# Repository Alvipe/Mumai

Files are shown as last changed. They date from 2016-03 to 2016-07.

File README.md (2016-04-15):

# Mumai
Mumai is a muscle-machine interface which uses EMG signals to control electronic or mechatronic devices.

<p align="center">
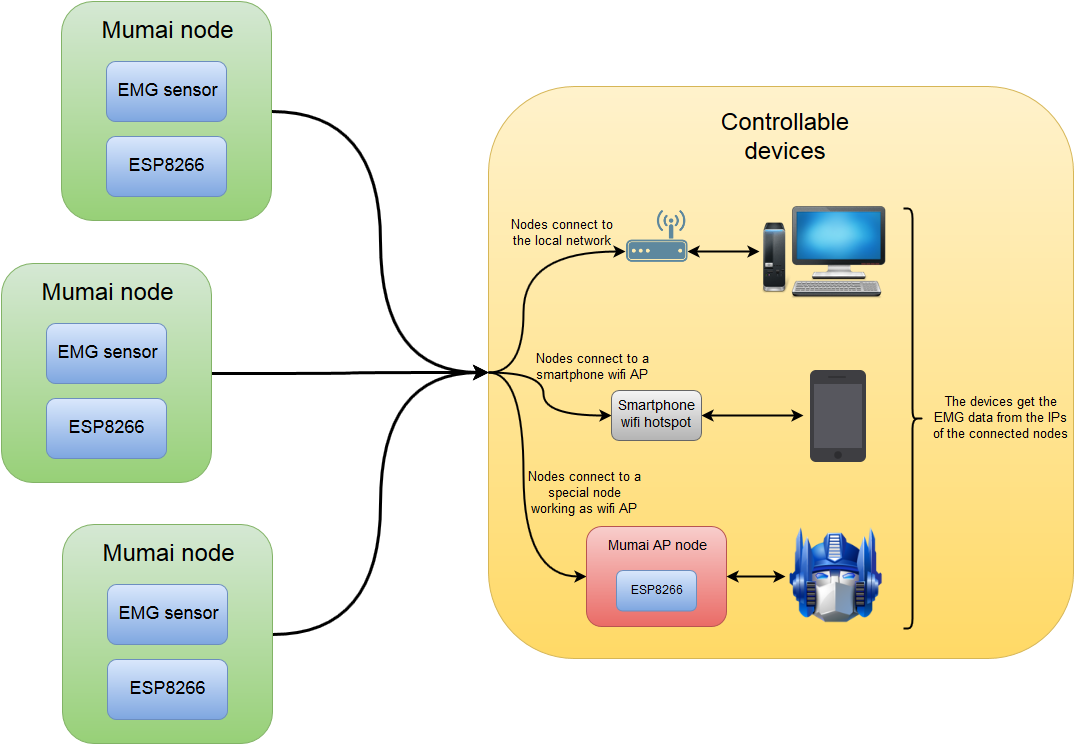
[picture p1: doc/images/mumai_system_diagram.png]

</p>

# License
<br />This work is licensed under a <a rel="license" href="http://creativecommons.org/licenses/by-sa/4.0/">Creative Commons Attribution-ShareAlike 4.0 International License</a>.

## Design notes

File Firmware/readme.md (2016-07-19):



To upload the firmware, use [PlatformIO](http://platformio.org/).

```bash
~/Mumai$ cd Firmware/NodeMCU
~/Mumai/Firmware/NodeMCU$ platformio run --target upload
```

The *mumai_testing.ino* file inside the *src* directory can also be uploaded with the Arduino IDE.

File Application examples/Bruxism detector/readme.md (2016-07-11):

To upload the firmware, use [PlatformIO](http://platformio.org/).

```bash
~/Mumai$ cd "Application examples"/"Bruxism detector"
~/Mumai/Application examples/Bruxism detector$ platformio run --target upload
```

The *bruxism_detector.ino* file inside the *src* directory can also be uploaded with the Arduino IDE.

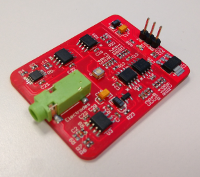
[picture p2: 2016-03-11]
doc/images/mumai.png

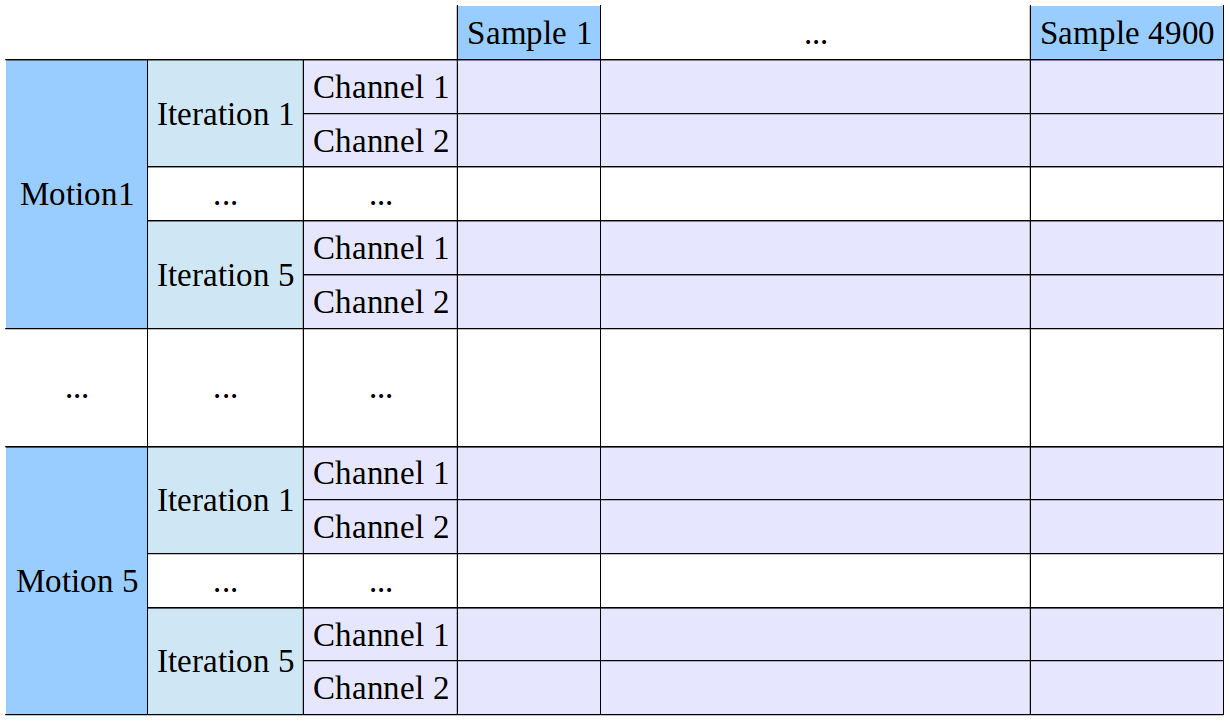
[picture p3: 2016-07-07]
doc/images/emg_data_matrix.png

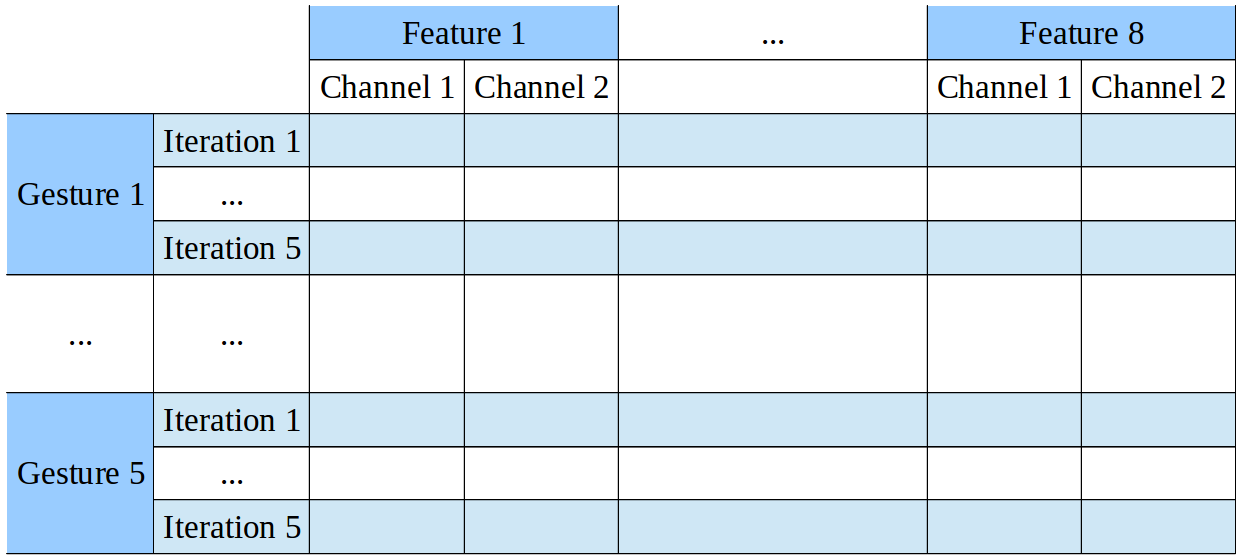
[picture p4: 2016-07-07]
doc/images/feature_matrix.png

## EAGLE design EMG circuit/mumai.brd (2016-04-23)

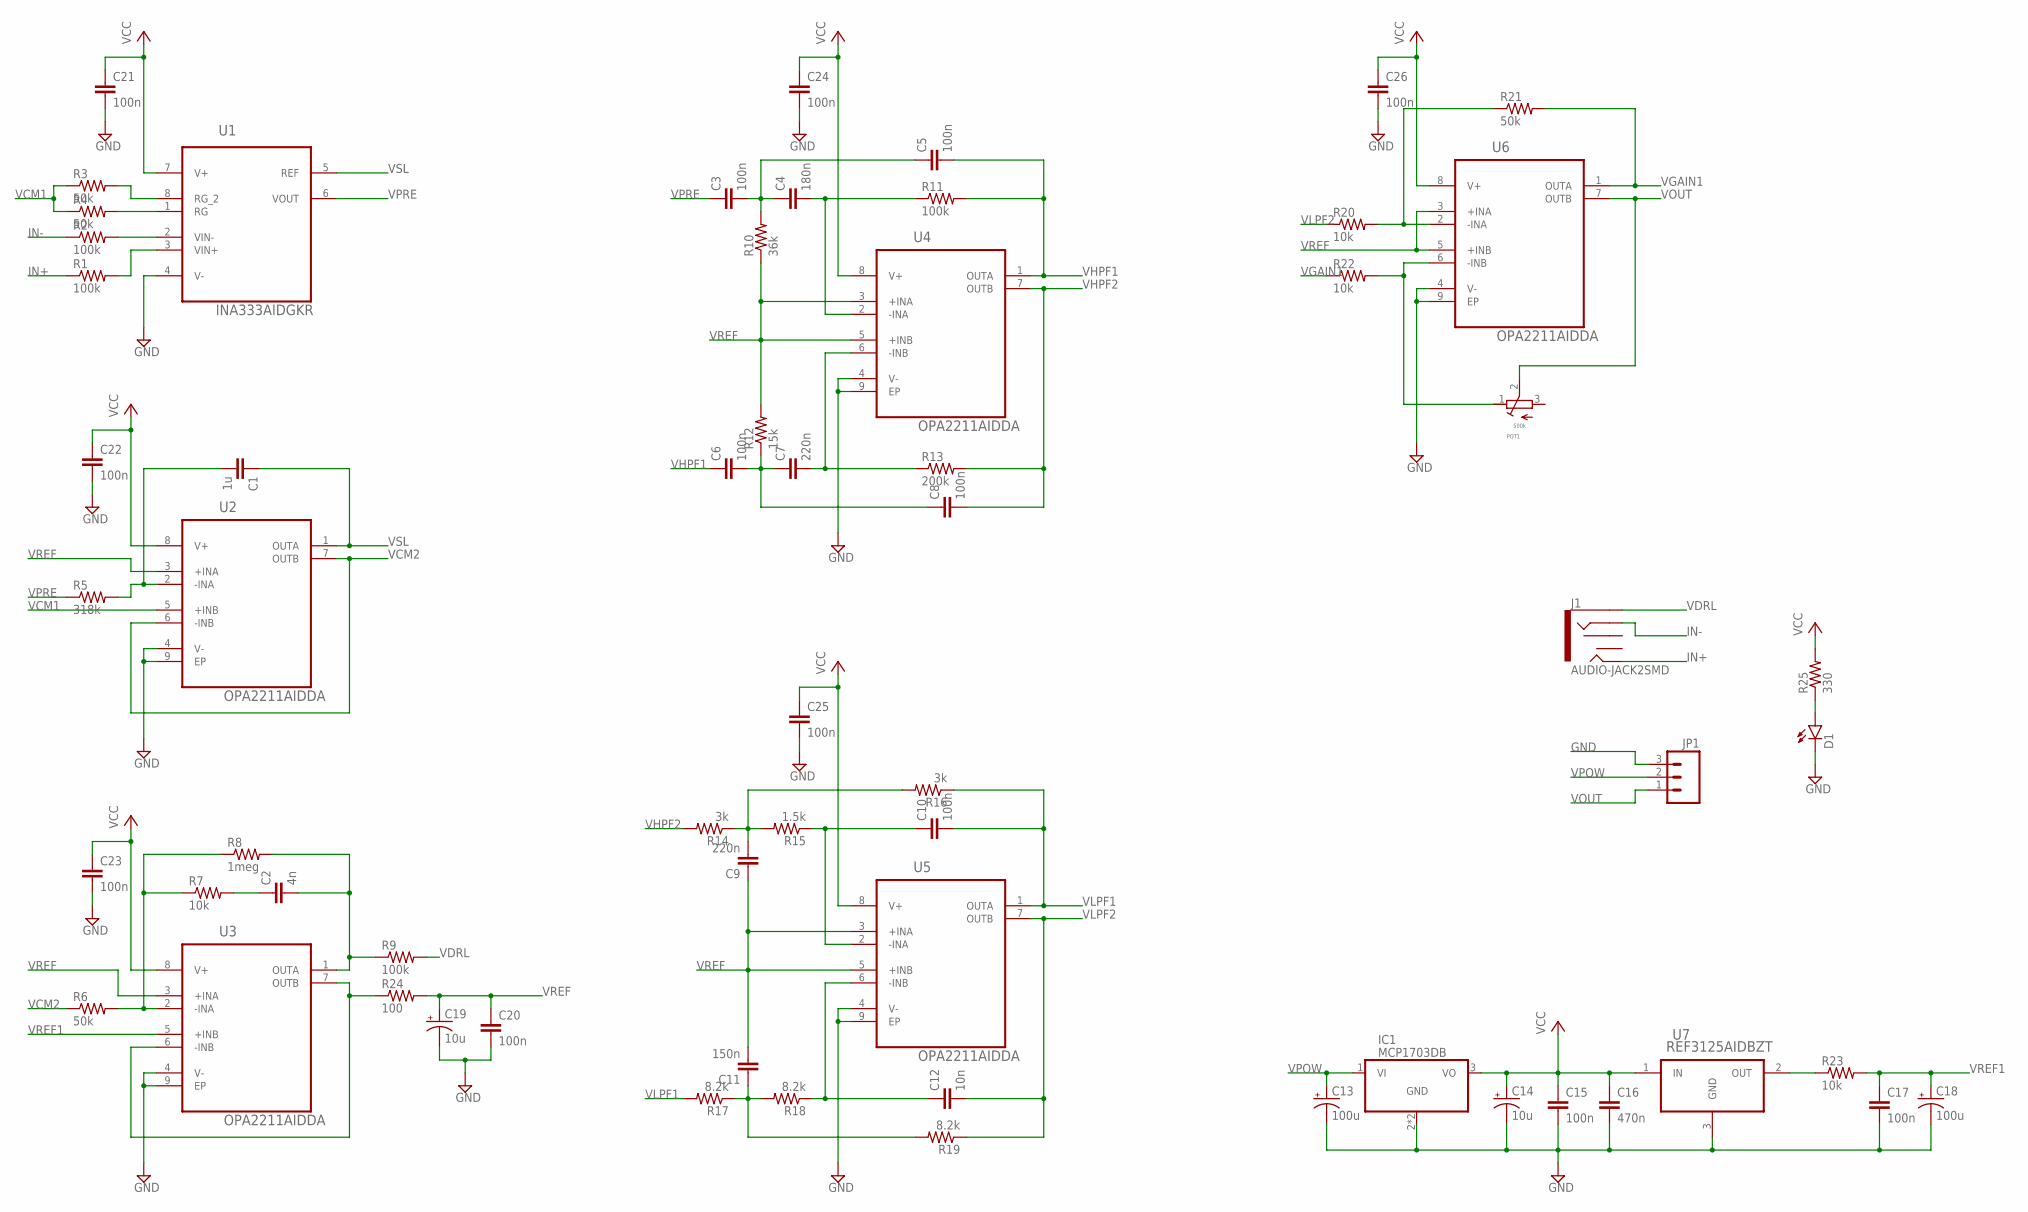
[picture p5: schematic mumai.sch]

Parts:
C1: 1u; 0402-CAP
C2: 4n; 0402-CAP
C3, C5, C6, C8, C10, C15, C17, C20, C21, C22, C23, C24, C25, C26: 100n; 0402-CAP
C4: 180n; 0402-CAP
C7, C9: 220n; 0402-CAP
C11: 150n; 0402-CAP
C12: 10n; 0402-CAP
C13, C18: 100u; EIA3216
C14, C19: 10u; EIA3216
C16: 470n; 0402-CAP
D1: LED0603; LED-0603
IC1: MCP1703DB; SOT223
J1: AUDIO-JACK2SMD; AUDIO-JACK-3.5MM-SMD
JP1: M03PTH; 1X03
POT1: 500k; BOURN_SMD_POTENTIOMETER
R1, R2, R9, R11: 100k; 0402-RES
R3, R4, R6, R21: 50k; 0402-RES
R5: 318k; 0402-RES
R7, R20, R22, R23: 10k; 0402-RES
R8: 1meg; 0402-RES
R10: 36k; 0402-RES
R12: 15k; 0402-RES
R13: 200k; 0402-RES
R14, R16: 3k; 0402-RES
R15: 1.5k; 0402-RES
R17, R18, R19: 8.2k; 0402-RES
R24: 100; 0402-RES
R25: 330; 0402-RES
U1: INA333AIDGKR; SOP65P490X110-8N
U2, U3, U4, U5, U6: OPA2211AIDDA; SOIC127P600X170-9N
U7: REF3125AIDBZT; SOT95P237X112-3N

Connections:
GND: C13.C (-), C14.C (-), C15.2, C16.2, C17.2, C18.C (-), C19.C (-), C20.2, C21.2, C22.2, C23.2, C24.2, C25.2, C26.2, D1.C, IC1.2 (GND), IC1.4 (GND), JP1.3, U1.4 (V-), U2.4 (V-), U2.9 (EP), U3.4 (V-), U3.9 (EP), U4.4 (V-), U4.9 (EP), U5.4 (V-), U5.9 (EP), U6.4 (V-), U6.9 (EP), U7.3 (GND)
IN+: J1.TIP, R1.1
IN-: J1.RING, R2.1
unnamed: R1.2, U1.3 (VIN+)
unnamed: R2.2, U1.2 (VIN-)
unnamed: R20.2, R21.1, U6.2 (-INA)
unnamed: R4.2, U1.1 (RG)
unnamed: R6.2, R7.1, R8.1, U3.2 (-INA)
unnamed: C1.2, R5.2, U2.2 (-INA)
unnamed: C4.2, R11.1, U4.2 (-INA)
unnamed: C2.1, R7.2
unnamed: C2.2, R8.2, R9.1, U3.1 (OUTA)
unnamed: C3.2, C4.1, C5.1, R10.2
unnamed: C10.1, R15.1, U5.2 (-INA)
unnamed: C9.2, R14.1, R15.2, R16.2
unnamed: C7.2, R13.1, U4.6 (-INB)
unnamed: C6.2, C7.1, C8.1, R12.1
unnamed: C12.1, R18.1, U5.6 (-INB)
unnamed: C11.1, R17.1, R18.2, R19.2
unnamed: R3.2, U1.8 (RG_2)
unnamed: D1.A, R25.1
unnamed: POT1.1 (A), R22.2, U6.6 (-INB)
unnamed: R24.1, U3.6 (-INB), U3.7 (OUTB)
unnamed: R23.1, U7.2 (OUT)
VCC: C14.A (+), C15.1, C16.1, C21.1, C22.1, C23.1, C24.1, C25.1, C26.1, IC1.3 (VO), R25.2, U1.7 (V+), U2.8 (V+), U3.8 (V+), U4.8 (V+), U5.8 (V+), U6.8 (V+), U7.1 (IN)
VCM1: R3.1, R4.1, U2.5 (+INB)
VCM2: R6.1, U2.6 (-INB), U2.7 (OUTB)
VDRL: J1.SLEEVE, R9.2
VGAIN1: R21.2, R22.1, U6.1 (OUTA)
VHPF1: C5.2, C6.1, R11.2, U4.1 (OUTA)
VHPF2: C8.2, R13.2, R14.2, U4.7 (OUTB)
VLPF1: C10.2, R16.1, R17.2, U5.1 (OUTA)
VLPF2: C12.2, R19.1, R20.1, U5.7 (OUTB)
VOUT: JP1.1, POT1.2 (S), U6.7 (OUTB)
VPOW: C13.A (+), IC1.1 (VI), JP1.2
VPRE: C3.1, R5.1, U1.6 (VOUT)
VREF: C9.1, C11.2, C19.A (+), C20.1, R10.1, R12.2, R24.2, U2.3 (+INA), U3.3 (+INA), U4.3 (+INA), U4.5 (+INB), U5.3 (+INA), U5.5 (+INB), U6.3 (+INA), U6.5 (+INB)
VREF1: C17.1, C18.A (+), R23.2, U3.5 (+INB)
VSL: C1.1, U1.5 (REF), U2.1 (OUTA)

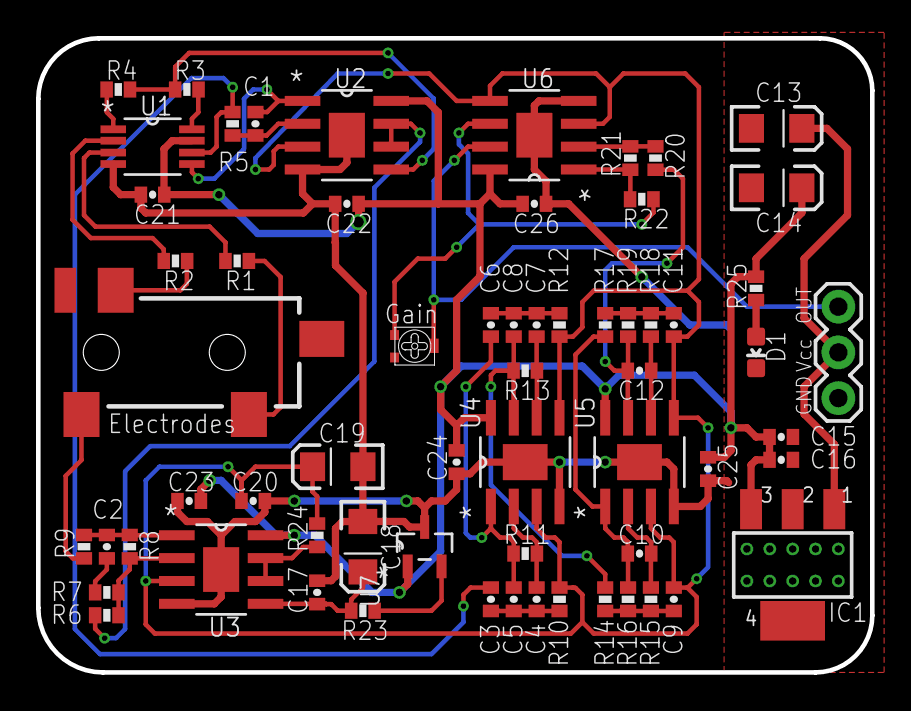
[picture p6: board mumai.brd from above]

Board: 2 copper layers, 46.3 x 35.2 mm, 63 parts (0 on the bottom side), 39 nets.

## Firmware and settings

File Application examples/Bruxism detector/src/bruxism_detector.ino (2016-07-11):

#include <MsTimer2.h>

static const unsigned int EMG_CH1 = 0;
static const unsigned int buzzerPin = 9;
static const unsigned int ledPin = 13;
static const unsigned int sampleTime = 1;
static const double adcRef= 5.00;
static const unsigned int adcRes = 1023;
static const double adcConv = adcRef/adcRes;

volatile unsigned int emg = 0;
double emgMean = 0.00;
double emgMovav = 0.00;
double emgMvc = 0.00;
volatile unsigned int sOK = 0;
unsigned int i = 0, k = 0;

/* sampling reads the ADC every 1 ms with the MsTimer2 interrupt. */
void sampling()
{
    emg = analogRead(EMG_CH1);
    sOK = 1; // sOK indicates that there is a new sample
}

/* meanCalc computes the mean value of the EMG signal during a period of
meanSamples. The mean value of the signal is its baseline. This value is
subtracted from the measured EMG signals to have a baseline of 0 V. */
void meanCalc(unsigned int meanSamples)
{
    while(i < meanSamples)
    {
        delayMicroseconds(50);
        if(sOK==1)
        {
            sOK = 0;
            i++;
            emgMean = emgMean + emg*adcConv;
        }
    }
    i = 0;
    emgMean = emgMean/meanSamples;
}

/* movAv computes the running moving average of the EMG signal. First, the
baseline of the signal is lowered to 0 V, to be able to rectify it. The running
moving average rectifies and smooths the signal (acts as a low pass filter),
returning the amplitude of the signal. */
void movAv()
{
    double emgZero = emg*adcConv - emgMean; // Signal with 0 V baseline
    emgMovav = emgMovav*0.99 + abs(emgZero)*0.01; // Rectified and smoothed signal
}

/* mvcCalc computes the maximum voluntary contraction, the maximum force the
user is able to exert. This value is used to compute the activation threshold */
void mvcCalc(unsigned int mvcSamples)
{
    while(i < mvcSamples)
    {
        delayMicroseconds(50);
        if(sOK==1)
        {
            sOK = 0;
            i++;
            movAv();
            if(emgMovav > emgMvc) {
                emgMvc = emgMovav;
            }
        }
    }
    i = 0;
    emgMovav = 0.00;
}

/* blinkLED blinks a led "repeat" times with a "bTime" interval between on and off */
void blinkLED(unsigned int repeat,unsigned int bTime)
{
    for(i=0;i<repeat;i++)
    {
        digitalWrite(ledPin,HIGH);
        delay(bTime);
        digitalWrite(ledPin,LOW);
        delay(bTime);
    }
}

void setup() {
    pinMode(EMG_CH1,INPUT);
    pinMode(ledPin,OUTPUT);
    pinMode(buzzerPin,OUTPUT);
    MsTimer2::set(sampleTime, sampling);
    MsTimer2::start();
    Serial.begin(250000);

    /* System calibration */
    delay(5000);
    /* Calibration step #1: calculate the baseline of the signal during 30 s */
    blinkLED(1,500); // LED indicates calibration step #1 start
    meanCalc(30000);
    blinkLED(1,500); // LED indicates calibration step #1 end
    delay(1000);
    /* Calibration step #2: calculate the maximum voluntary contraction during 5 s*/
    blinkLED(2,500); // LED indicates calibration step #2 start
    mvcCalc(5000);
    blinkLED(2,500); // LED indicates calibration step #2 end
}

void loop() {
    movAv(); // Gets the amplitude of the measured EMG signal

    /* If the amplitude of the EMG signal is greater that a 35% of the MVC, the
    user is warned with a visual alert (LED) and an audible alarm (buzzer). */
    if(emgMovav > 0.35*emgMvc) {
        digitalWrite(ledPin, HIGH);
        analogWrite(buzzerPin,500); // Adjusts the volume of the buzzer
        delayMicroseconds(1275); // Sets the tone of the buzzer
    }
    else {
        digitalWrite(ledPin, LOW);
        analogWrite(buzzerPin,0);
        delayMicroseconds(1275);
    }
    // delay(2);
    // Serial.println(emgMovav);
}

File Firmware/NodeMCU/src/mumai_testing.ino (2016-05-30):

/* This code is for testing the connection of a NodeMCU (ESP8266-based board) with a LTC2440 (24-bit ADC)
and for testing different ways of sending data wirelessly to improve transmission time.
Data is received at the PC through a PuTTY terminal connected to the IP address of the NodeMCU.*/

#include <ESP8266WiFi.h> // https://github.com/esp8266/Arduino
#include <SPI.h>

// With the union data type, the EMG data is stored as a float and as a byte array simultaneously
static const int dataSize = sizeof(float);
typedef union {
    float floating;
    uint8_t binary[dataSize];
} binaryFloat;

// WiFi parameters
const char* ssid = "yourssid";
const char* password = "yourpassword";
WiFiServer server(80);

// ADC parameters
static const double Vref = 4.54; //ADC external reference voltage
// Set I/O pins used in addition to clock, data in, data out
const byte slaveSelectPin = 5;  // digital pin 5 for /CS
const byte resetPin = 16;  // digital pin 16 for /RESET

/* SpiRead code by John Beale
(taken and adapted from http://www.steveluce.com/24bits/Applications%20of%20the%20LTC%2024%20bit%20ADC.html) */
float SpiRead(void) {
    long result = 0;
    float v = 0;
    byte sig = 0;
    byte b;

    digitalWrite(slaveSelectPin,LOW);   // take the SS pin low to select the chip
    delayMicroseconds(1);              // probably not needed, only need 25 nsec delay

    b = SPI.transfer(0xff); // B3
    if ((b & 0x20) ==0) sig=1; // is input negative?
    b &=0x1f; // discard bits 29, 30, 31
    result = b;
    result <<= 8;
    b = SPI.transfer(0xff); // B2
    result |= b;
    result = result<<8;
    b = SPI.transfer(0xff); // B1
    result |= b;
    result = result<<8;
    b = SPI.transfer(0xff); // B0
    result |= b;

    digitalWrite(slaveSelectPin,HIGH); // take the SS pin high to de-select the chip

    if (sig) result |= 0xf0000000; // if input is negative, insert sign bit (0xf0.. or 0xe0... ?)
    result = result>>4; // truncate lowest 4 bits
    v = result*(Vref/2)/16777216; //Vadc*(Vref/2)/2^24
    return(v);
}

void setup()
{
    Serial.begin(115200);
    pinMode (slaveSelectPin, OUTPUT);
    pinMode (resetPin, OUTPUT);
    digitalWrite(resetPin,HIGH);  // reset is active low

    // Configure SPI
    SPI.begin(); // initialize SPI, covering MOSI,MISO,SCK signals
    SPI.setBitOrder(MSBFIRST);  // data is clocked in MSB first
    SPI.setDataMode(SPI_MODE0);  // SCLK idle low (CPOL=0), MOSI read on rising edge (CPHI=0)
    SPI.setClockDivider(SPI_CLOCK_DIV16);  // SPI_CLOCK_DIV16 gives me a 1.0 MHz SPI clock, with 16 MHz crystal on Arduino

    // Connect to WiFi
    WiFi.mode(WIFI_STA);
    WiFi.begin(ssid, password);
    while (WiFi.status() != WL_CONNECTED) {
        delay(500);
        Serial.print(".");
    }
    server.begin();
    Serial.println("");
    Serial.println("WiFi connected");

    // Print some information of the ESP8266 module:
    Serial.print("IP address: ");
    Serial.println(WiFi.localIP());
    Serial.print("MAC address: ");
    Serial.println(WiFi.macAddress());
    Serial.print("ESP8266 ID: ");
    Serial.println(ESP.getChipId());
}

void loop()
{
    binaryFloat data;
    data.floating = 1.2345;
    uint8_t dataBuffer[400];
    for(int j=0;j<=400-dataSize;j=j+dataSize) {
        dataBuffer[j] = data.binary[0];
        dataBuffer[j+1] = data.binary[1];
        dataBuffer[j+2] = data.binary[2];
        dataBuffer[j+3] = data.binary[3];
    }
    unsigned long tictocs = 0;

    WiFiClient client = server.available();
    client.setNoDelay(1);
    while(client) {
        if(client.connected()) {
            Serial.println("Connected to client");
            for(int i=0;i<1000;i++) {
                // data.floating = SpiRead();
                unsigned long tic = micros();
                // client.println(data.floating,4);
                // client.write(&data.binary[0],4);
                client.write(&dataBuffer[0],400);
                unsigned long toc = micros();
                tictocs += toc - tic;
            }
            unsigned long meanTime = tictocs/1000;
            Serial.println(meanTime);
            tictocs = 0;
        }
        else {
            Serial.println("Client disconnected");
            client.stop();
        }
    }
    Serial.println("No client");
}

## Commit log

2016-02-26 Added EMG circuit files
    [mumai.brd, mumai.sch]
2016-04-23 Update EMG board
    [mumai.brd]

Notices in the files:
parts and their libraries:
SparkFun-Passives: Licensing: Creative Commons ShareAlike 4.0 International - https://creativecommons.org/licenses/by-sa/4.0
